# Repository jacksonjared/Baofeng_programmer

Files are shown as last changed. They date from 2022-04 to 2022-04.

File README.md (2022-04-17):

# Baofeng Programming Adapter

This board adapts the 5 volt USB port from a computer to 3V3 UART for use with programming Baofeng or similar chinese HTs. Most of these radios use a "Kenwood style" connector for programming; I have chosen to use separate 3.5mm and 2.5mm jacks as, annoyingly, several of the brands use non-standard spacing so as to make most cable incompatible. I have also elected to use a Silicon Labs chip to avoid the driver fiasco with the other common supplier of cheap UART bridge ICs.

## 3d

Within the folder labled '3d', you will find a .step file of the complete board and all its components, as well as models for the non-standard parts I used. I made a casing for this board to be 3D printed, but I currently do not have that file on hand. If I get a copy of it again sometime in the future, I will add it.

## gerber.zip

This is an archive of all the gerber files needed for manufacturing. I did not bother having this assembled in the factory so there is no BOM or pick-and-place file.

## main_board

I originally made this board in Kicad 5, and have since updated it to Kicad 6. I do not see anything obviously wrong with the project after converting, but I have not looked that close. If I notice any problems, I will fix them and push the change.

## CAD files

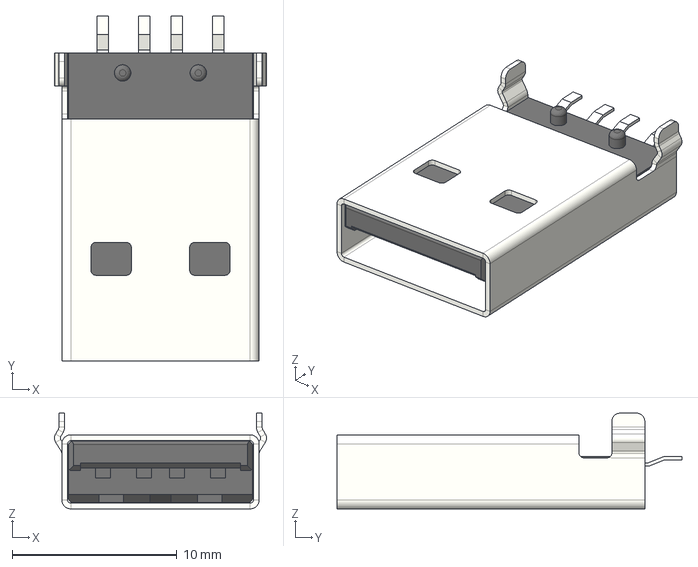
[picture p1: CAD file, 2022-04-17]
3d/1001-011-01101.step
12.9 x 21.0 x 5.82 mm

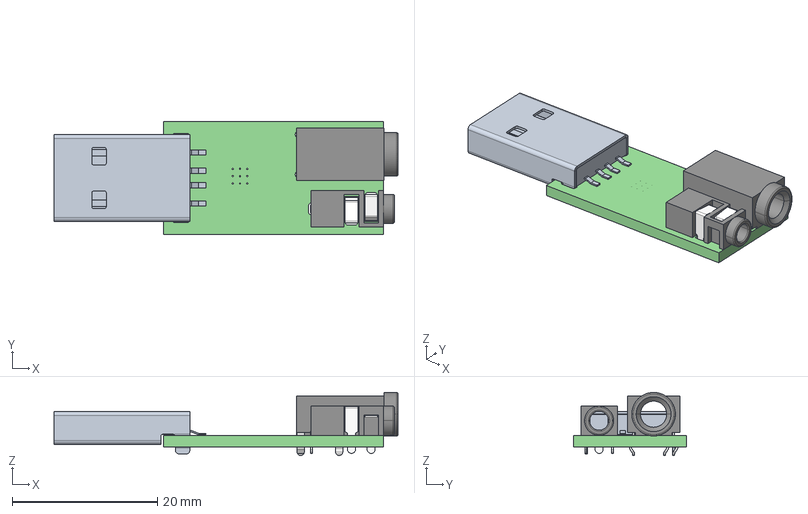
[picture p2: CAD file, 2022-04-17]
3d/baoProg.step
47.4 x 15.5 x 8.70 mm
_autosave-baoProg PCB

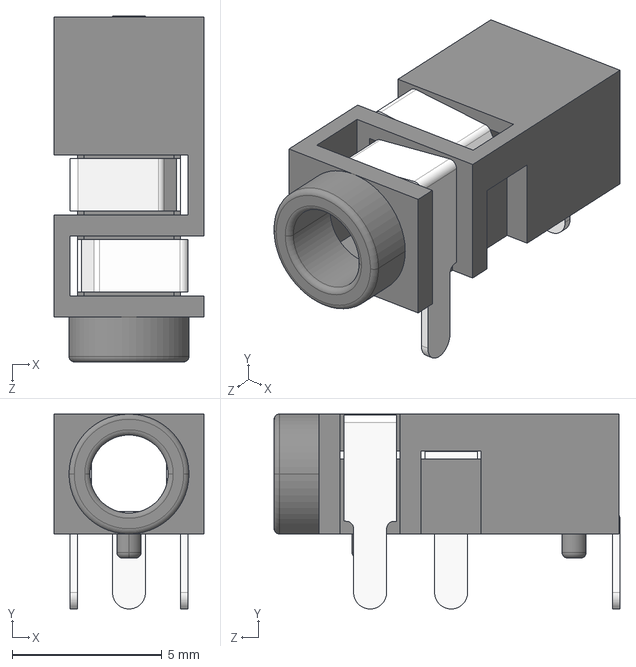
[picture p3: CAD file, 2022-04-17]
3d/STX-2000-3N_rA1.STEP
5.00 x 6.50 x 11.5 mm

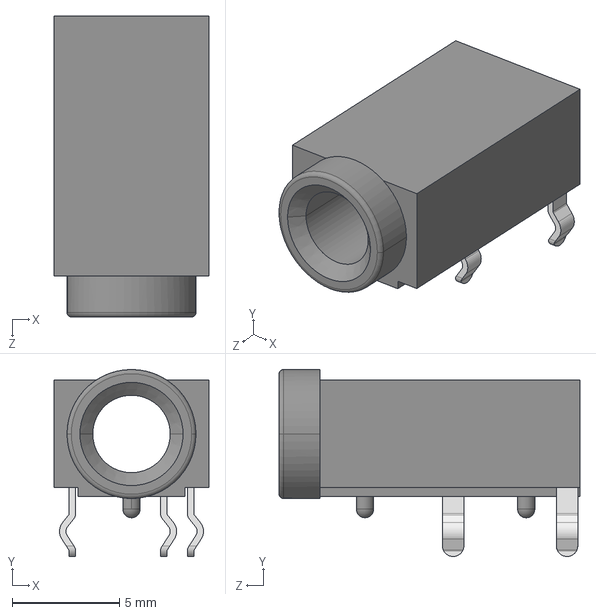
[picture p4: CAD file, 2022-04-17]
3d/STX-3000_rD3.STEP
7.20 x 8.70 x 14.0 mm

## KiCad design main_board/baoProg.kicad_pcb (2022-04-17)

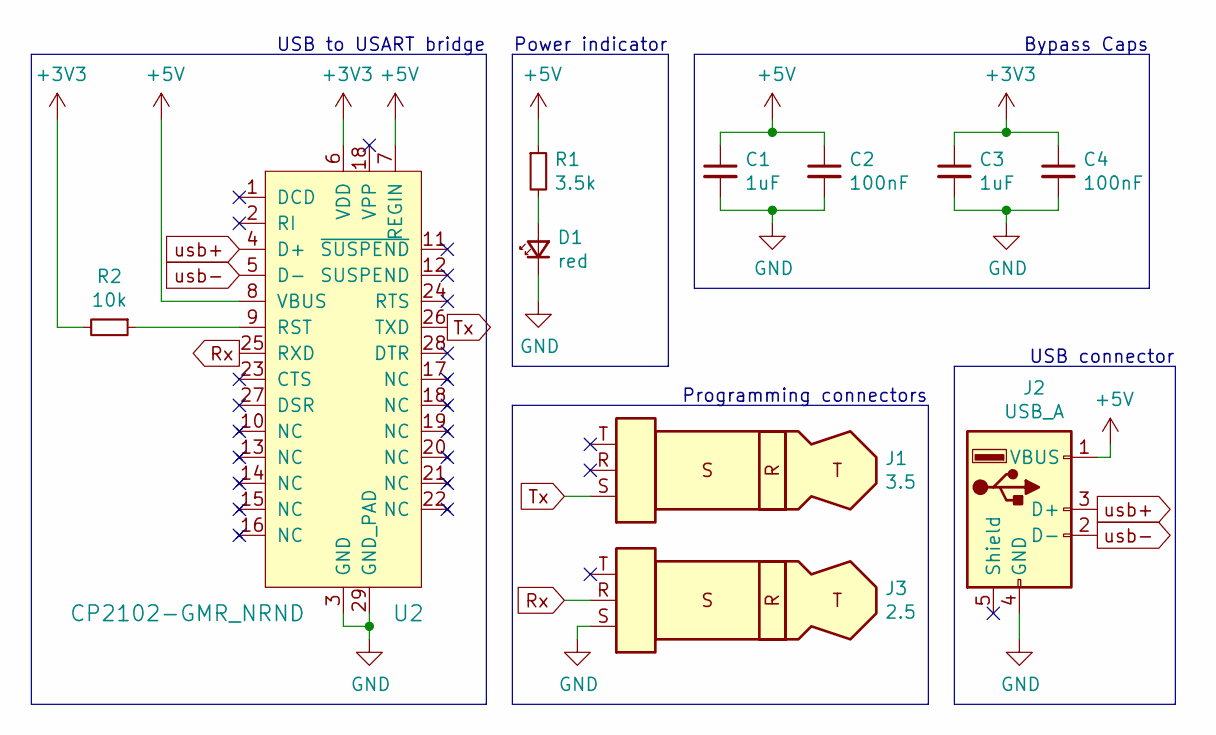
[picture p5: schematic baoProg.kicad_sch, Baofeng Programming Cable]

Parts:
C1, C3: 1uF; C_0603_1608Metric_Pad1.08x0.95mm_HandSolder
C2, C4: 100nF; C_0603_1608Metric_Pad1.08x0.95mm_HandSolder
D1: red; LED_0603_1608Metric_Castellated
J1: 3.5; STX-3000
J2: USB_A; USB_A_CNCTech_1001-011-01101_Horizontal_3d
J3: 2.5; STX-2000
R1: 3.5k; R_0805_2012Metric_Pad1.20x1.40mm_HandSolder
R2: 10k; R_0805_2012Metric_Pad1.20x1.40mm_HandSolder
U2: CP2102-GMR_NRND; QFN-28-1EP_5x5mm_P0.5mm_EP3.35x3.35mm_ThermalVias; MPN CP2102-GMR; Digi-Key_PN 336-1160-1-ND

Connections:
+3V3: C3.1, C4.1, R2.2, U2.6 (VDD)
+5V: C1.1, C2.1, J2.1 (VBUS), R1.1, U2.7 (REGIN), U2.8 (VBUS)
GND: C1.2, C2.2, C3.2, C4.2, D1.1 (K), J2.4 (GND), J3.S, U2.3 (GND), U2.29 (GND_PAD)
unnamed: D1.2 (A), R1.2
unnamed: R2.1, U2.9 (RST)
Rx: J3.R, U2.25 (RXD)
Tx: J1.S, U2.26 (TXD)
usb+: J2.3 (D+), U2.4 (D+)
usb-: J2.2 (D-), U2.5 (D-)

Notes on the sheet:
USB connector
Bypass Caps
Power indicator
USB to USART bridge
Programming connectors

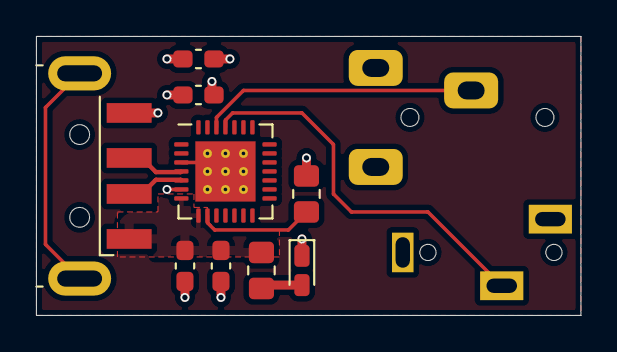
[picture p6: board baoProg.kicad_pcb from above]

Board: 4 copper layers, 30.2 x 15.5 mm, 11 parts (0 on the bottom side), 9 nets.
